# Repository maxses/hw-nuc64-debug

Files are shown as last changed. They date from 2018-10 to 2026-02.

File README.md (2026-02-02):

# NUC64DEBUG

## Overview

| | |
|:---|:---|
| Name | NUC64DEBUG |
| HW-Rev | v0.3.x |
| Docu | 20260117 |
| Dimensions| 17.30mm x 30.43mm |

Small adapter PCB to connect a STM32 based custom PCB via 10P-FPC with the STLink-part
of an Nucleo64-Board.

## PCB

| Top |  Bottom |
|:---|:---|
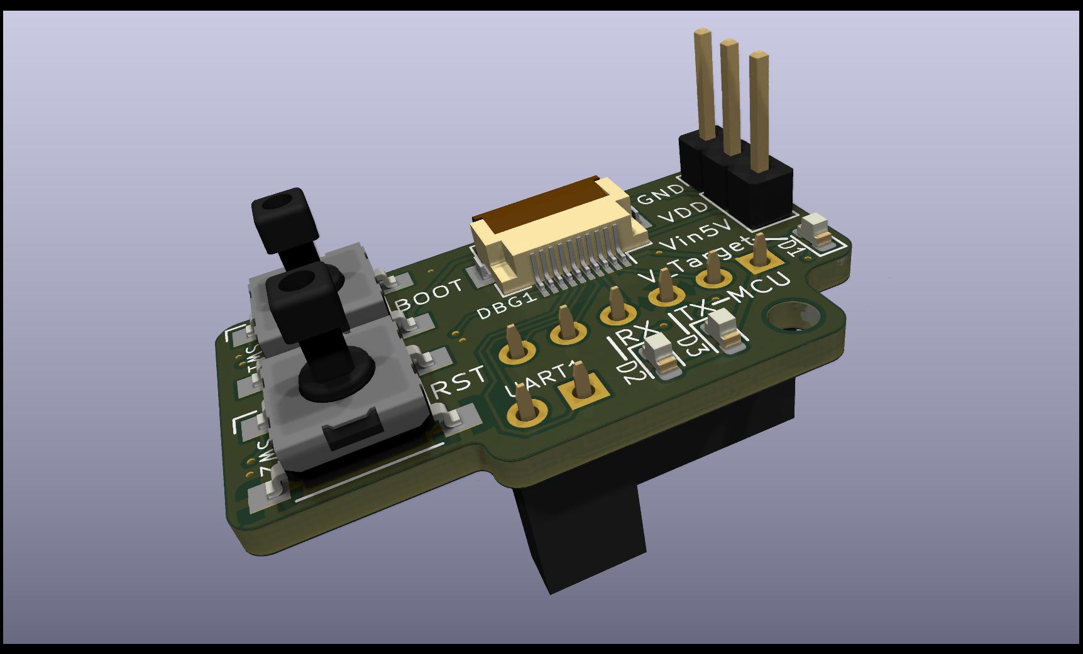
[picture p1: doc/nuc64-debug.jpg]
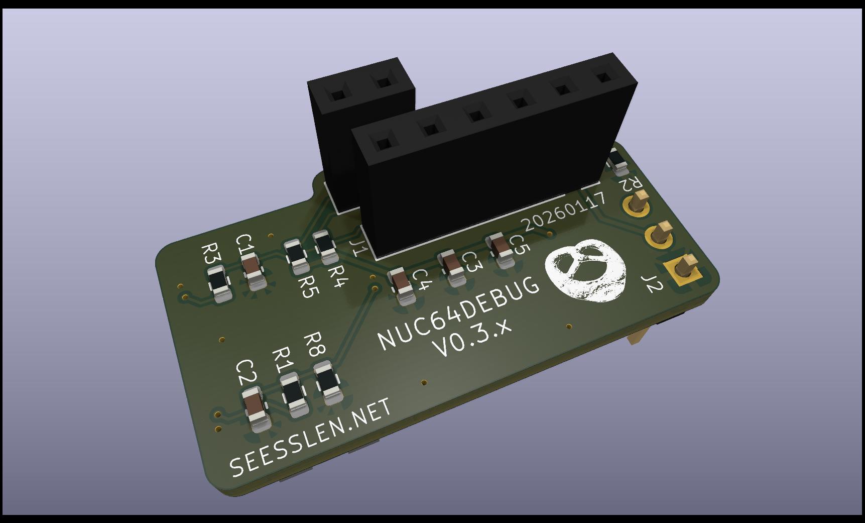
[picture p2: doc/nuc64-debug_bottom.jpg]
|  |  |

## Connectors

### DBG1

| Connector-pin |  Function |
|:---|:---|
| 1 | VDD Target |
| 2 | SWCLK |
| 3 | GND |
| 4 | SWDIO |
| 5 | NRST |
| 6 | NC (Reserved for SWO)  |
| 7 | UART TX (Target) |
| 8 | UART RX (Target) |
| 9 | VIN 5V |
| 10 | BOOT0 |

## J1

| Connector-pin |  Function |
|:---|:---|
| 1 | VDD |
| 2 | SWCLK |
| 3 | GND |
| 4 | SWDIO |
| 5 | NRST |
| 6 | SWO |

## UART1

| Connector-pin |  Function |
|:---|:---|
| 1 | TX (ST-Link / Host) -> yellow on adapter cable |
| 2 | RX (ST-Link / Host) -> red on adapter cable |

## Errata

* If you have problems with the  UART you may need to update firmware of STLink.
Version V2J20M4 did not work, after update to V2J38M27 problems disappeared.

* V0.2.x: Boot-Button not functional. Connect J2-Pin2(VDD) to button pad in the corner.

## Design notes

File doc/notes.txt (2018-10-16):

BOM
    Kable:
	(mouser) "Draht u. Kabel" -> "FFC- / FPC-Verbinder"
	Wurth Electronics 687710100002 
	0.5mm Type 2 10P 100mm length

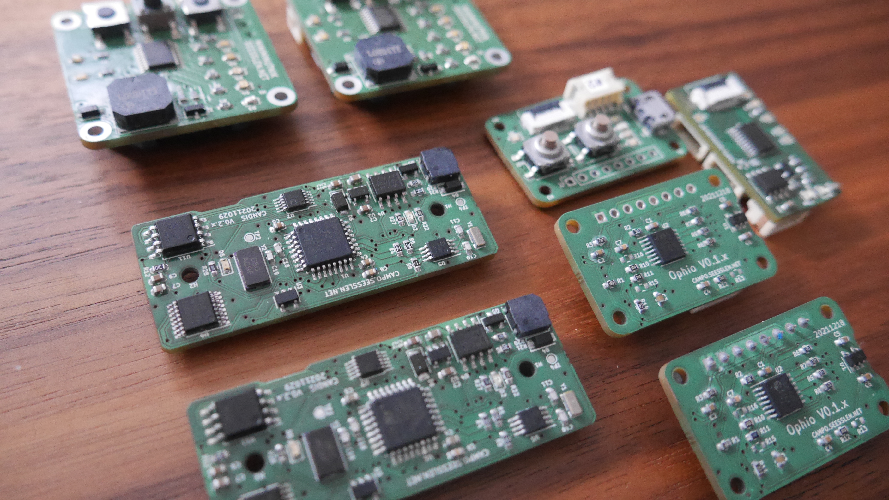
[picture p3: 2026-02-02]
doc/background.jpg

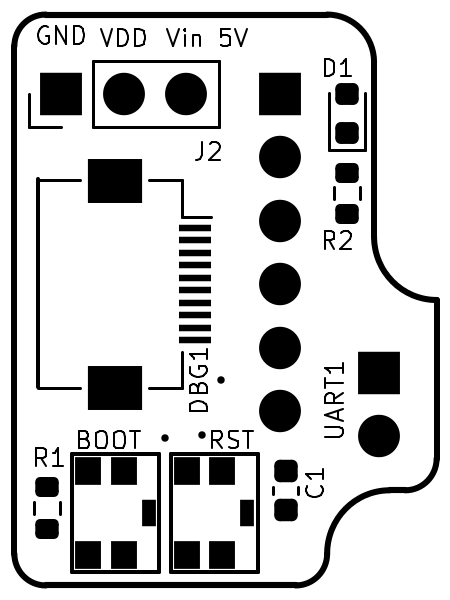
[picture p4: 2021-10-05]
doc/preview_top.png

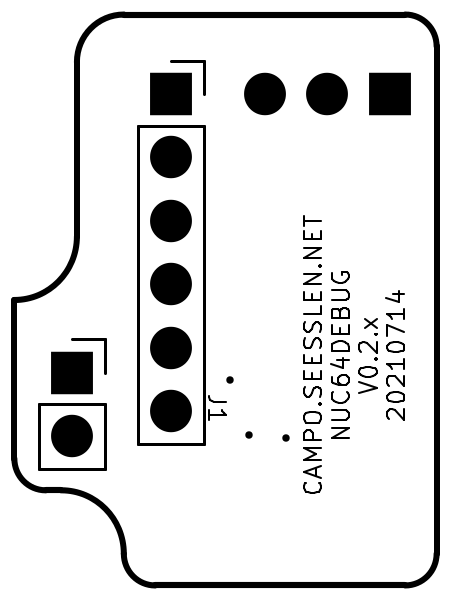
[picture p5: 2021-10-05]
doc/preview_bottom.png

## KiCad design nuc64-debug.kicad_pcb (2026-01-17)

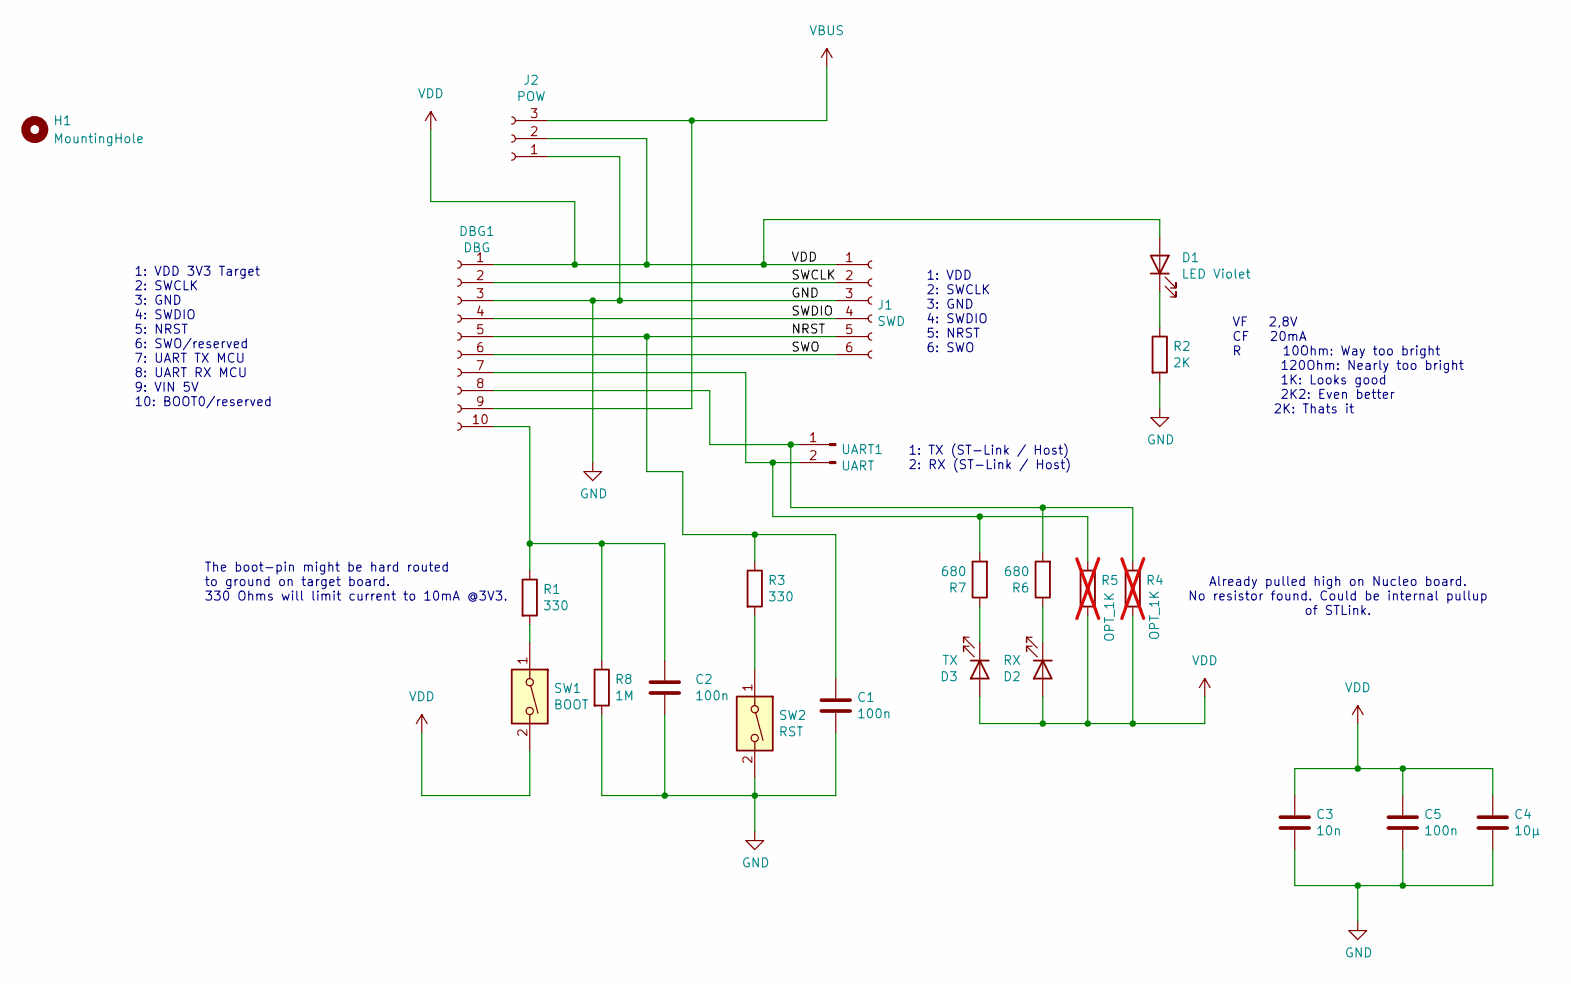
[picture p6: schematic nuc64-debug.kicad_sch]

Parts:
C1, C2, C5: 100n; C_0603_1608Metric
C3: 10n; C_0603_1608Metric
C4: 10µ; C_0603_1608Metric
D1: LED Violet; LED_0603_1608Metric
D2: RX; LED_0603_1608Metric
D3: TX; LED_0603_1608Metric
DBG1: DBG; Hirose_FH12-10S-0.5SH_1x10-1MP_P0.50mm_Horizontal
H1: MountingHole; MountingHole_2.2mm_M2_DIN965
J1: SWD; PinSocket_1x06_P2.54mm_Vertical
J2: POW; PinHeader_1x03_P2.54mm_Vertical
R1, R3: 330; R_0603_1608Metric
R2: 2K; R_0603_1608Metric
R4, R5: OPT_1K; R_0603_1608Metric; not fitted
R6, R7: 680; R_0603_1608Metric
R8: 1M; R_0603_1608Metric
SW1: BOOT; SW_SPST_Omron_B3FS-105xP
SW2: RST; SW_SPST_Omron_B3FS-105xP
UART1: UART; PinSocket_1x02_P2.54mm_Vertical

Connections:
/NRST: C1.1, DBG1.5, J1.5, R3.1
/SWCLK: DBG1.2, J1.2
/SWDIO: DBG1.4, J1.4
/SWO: DBG1.6, J1.6
GND: C1.2, C2.2, C3.2, C4.2, C5.2, DBG1.3, J1.3, J2.1, R2.2, R8.2, SW2.2
unnamed: D1.1 (K), R2.1
unnamed: D2.1 (K), R6.1
unnamed: D3.1 (K), R7.1
unnamed: DBG1.7, R5.1, R7.2, UART1.2
unnamed: DBG1.8, R4.1, R6.2, UART1.1
unnamed: C2.1, DBG1.10, R1.1, R8.1
unnamed: R1.2, SW1.1
unnamed: R3.2, SW2.1
VBUS: DBG1.9, J2.3
VDD: C3.1, C4.1, C5.1, D1.2 (A), D2.2 (A), D3.2 (A), DBG1.1, J1.1, J2.2, R4.2, R5.2, SW1.2

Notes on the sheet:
1: TX (ST-Link / Host) 2: RX (ST-Link / Host)
VF 2,8V CF 20mA R 10Ohm: Way too bright 120Ohm: Nearly too bright 1K: Looks good 2K2: Even better 2K: Thats it
The boot-pin might be hard routed to ground on target board. 330 Ohms will limit current to 10mA @3V3.
1: VDD 3V3 Target 2: SWCLK 3: GND 4: SWDIO 5: NRST 6: SWO/reserved 7: UART TX MCU 8: UART RX MCU 9: VIN 5V 10: BOOT0/reserved
1: VDD 2: SWCLK 3: GND 4: SWDIO 5: NRST 6: SWO
Already pulled high on Nucleo board. No resistor found. Could be internal pullup of STLink.

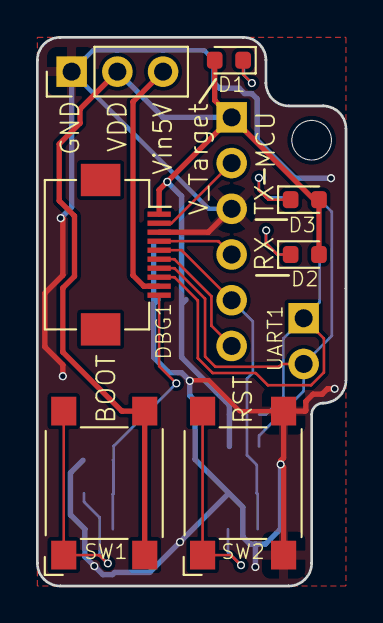
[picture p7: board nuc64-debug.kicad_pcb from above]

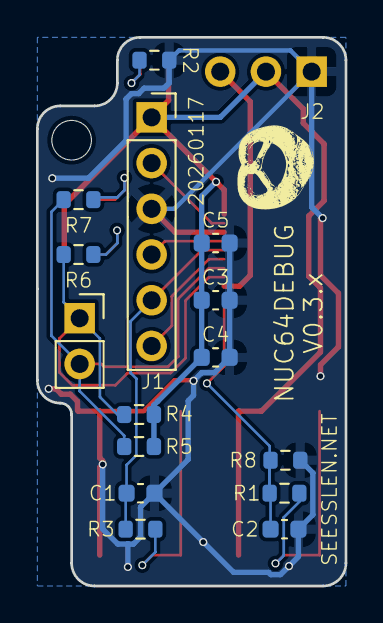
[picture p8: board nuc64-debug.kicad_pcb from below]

Board: 2 copper layers, 17.1 x 30.5 mm, 23 parts (15 on the bottom side), 15 nets.

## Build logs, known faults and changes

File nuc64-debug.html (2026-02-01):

# nuc64-debug/nuc64-debug.kicad_sch

2026-02-01T08:36:21+0100

Component Count:22

Ref | Qnty | Value | Part | Warehouse
C1, C2, C5 | 3 | 100n | Device:C
C3 | 1 | 10n | Device:C
C4 | 1 | 10µ | Device:C
D1 | 1 | LED Violet | Device:LED
D2 | 1 | RX | Device:LED
D3 | 1 | TX | Device:LED
DBG1 | 1 | DBG | Connector:Conn_01x10_Socket
J1 | 1 | SWD | Connector:Conn_01x06_Socket
J2 | 1 | POW | Connector:Conn_01x03_Socket
R1, R3 | 2 | 330 | Device:R
R2 | 1 | 2K | Device:R
R4, R5 | 2 | OPT_1K | Device:R
R6, R7 | 2 | 680 | Device:R
R8 | 1 | 1M | Device:R
SW1 | 1 | BOOT | Switch:SW_DIP_x01
SW2 | 1 | RST | Switch:SW_DIP_x01
UART1 | 1 | UART | Connector:Conn_01x02_Pin

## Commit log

2018-10-06 initial import
    [nuc64-debug.kicad_pcb, nuc64-debug.sch]
2018-10-06 added git ignore file
    [nuc64-debug.kicad_pcb]
2018-10-06 added some grounding vias
    [nuc64-debug.kicad_pcb]
2018-10-16 fixed drawings
    [nuc64-debug.kicad_pcb]
2021-07-14 First draft for 0.2.x
    Uart TX/RX have been swapped
    Buttons for Reset/Boot0 have been added
    Pinheader for power pins has been added
    [nuc64-debug.kicad_pcb, nuc64-debug.sch]
2021-07-14 make the design category 'easy' for aisler design rules
    [nuc64-debug.kicad_pcb]
2026-01-17 [#32/#388] Boot0-button pulls high; updated symbols
    [nuc64-debug.kicad_pcb, nuc64-debug.kicad_sch, nuc64-debug.sch]
2026-01-17 Finished routing
    [nuc64-debug.kicad_pcb]
2026-01-17 Fixed trace width
    [nuc64-debug.kicad_pcb, nuc64-debug.kicad_sch]
2026-01-17 Added UART LEDs
    [nuc64-debug.kicad_pcb, nuc64-debug.kicad_sch]
2026-01-17 Added mounting hole for soldering
    [nuc64-debug.kicad_pcb, nuc64-debug.kicad_sch]
2026-01-17 Added Brezel
    [nuc64-debug.kicad_pcb]
2026-01-17 Updated BOM
    [nuc64-debug.kicad_pcb]
2026-01-17 Made UART pullups optional
    [nuc64-debug.kicad_pcb, nuc64-debug.kicad_sch]
2026-02-02 Updated values for R6/R7
    [nuc64-debug.kicad_sch]
